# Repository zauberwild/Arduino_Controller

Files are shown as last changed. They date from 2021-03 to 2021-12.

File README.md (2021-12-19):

# Arduino_Controller

## Intro

This is a little project i did with a joystick breakout board, that usually would be used with the Micro:Bit platform. I got this breakout board for Christmas, however I don't have any Micro:Bit controllers (and didn't want to get into these ones), so I tried to make it compatible with Arduinos. For that, I broke off the connector on the PCB and soldered my own wires to it to connect to an Arduino Pro Micro.

## Communication and using the controller

### The LED

Below the jumper connector is a tiny groove, behind which a led is hiding. The led indicates the working mode:

1. Blink: controller mode
2. Blinks: serial with continuous data
3. Blinks: serial with data on event

The led will blink every time on when changing the modes and once at startup.

### Settings

The controller will as default act as a real controller to the computer. However, the serial port is always open (Baud: 9600), so you can apply some settings at any time:

1. **Communication mode:** The arduino can send the 'raw' data over its serial ports instead of acting like a real controller. In that mode, the arduino sends all data both over USB and the jumper connectors next to it at the same time, as they are the same port. More on how to process the incoming data later. You can change between these modes by simply sending `com_mode=controller` or `com_mode=serial`.
2. **Sending mode:** In serial mode, you can change between a continuous data stream with all data and data on event, which means the arduino only sends somethings, when something changed. Change this with `sending_mode=continuous` and `sending_mode=onEvent`.
3. **Joystick mode:** Sometimes having a D-pad is more useful than a joystick. For this case, you can switch between analogue and digital values for the Joystick. This settings only makes a difference in controller mode. In serial, both the analogue and digital values are send, more info on that below. That setting is changed by `joystick_mode=analog` and `joystick_mode=digital`.

The arduino will always respond with the setting you just declared or with an error, when the command couldn't be understood. You don't have to worry about newline trailers and spaces though, these are automatically removed.

**However**, I also wrote a python script that makes is it easier to change the settings. (See down below)

### Using as a controller

It's _almost_ plug'n'play. You will need to configure it though, for example in Steam's controller settings, because an Arduino is not a standard and well-known gaming controller. You might want to configure both the Joystick and the D-pad, so you will need to change modes during the process.

### Using the serial port

As previously said, you can both use the USB-port and the jumper connectors. The pinout of the latter is seen in this picture:

The arduino has a 5V operating voltage, so be warned when combining it with a 3.3V micro-controller.

*I also might write a library for arduino that would take care of all the communicating below*.

#### continuous

The data is presented as one long string, each character representing one button. The string looks something like this: `00010010x25y-103z11000`. The order of buttons in front of the letters is as follows:
`up - down - left - right - mode - l1 - r1`
Between the letters are the analogue values, reaching from -127 to 127 (left - right and up - down, meaning a movement up returns a negative number). Because the length of these numbers can change, they are bordered by letters. `'x' - potiX - 'y' - potiY - 'z'`.
After the letters are the button inside the joystick, or "z-axis", and the digital (`0/1`)values of the joystick for each direction:
`potiZ - potiUp - potiDown - potiLeft - potiRight`

#### onEvent

In that mode, the data is only send when something changes. In that case, the arduino will send the name of the button (you can see the names in the picture below), followed by a number with the new value. For example: 
- `up1` (the UP-button is pressed)
- `left0` (the LEFT-button is released)
- `potiX68` (the joystick is moved about half ways to the right)

## Materials

| Item | Price | Link (on where I found it) |
| --- | --- | --- |
| Arduino Pro Micro | 6.90€ | https://www.berrybase.de/raspberry-pi-co/arduino/boards/kompatibler-arduino-pro-micro-mit-atmel-mega-32u4-prozessor |
| Keyestudio Joystick Breakout Board for Micro:Bit | 6.41€ 9.00$ | https://www.keyestudio.com/products/keyestudio-joystick-breakout-board-for-bbc-microbit-1 |

The Arduino Pro Micro is not an official Arduino board, I think, but it uses the same processor as the Arduino Leonardo, the Atmega32u4, and appears as such. To use this board, you simply can choose the Arduino Leonardo as the board and program it rightaway.

additional material:

- 2 M3 screws, 10-15mm long
- a 3D-Printer and filament
- wires, soldering iron and tin
- two tiny breakout board push-buttons and a led

## 3D-Printing and Assembly

All the necessary .stl-files are in /cad/final. You can also find the Fusion 360 and STEP files there. For the printing I used an Anycubic I3 Mega, with silver PLA on 0.12mm layer height. All parts together took a little bit more than 24 hours, test pieces not included.

The breakout board should fit on the standoffs of the lower side part. The Led goes under the breakout board in it's hole and might needs to glued. It's then connected to GND and the Led-Pin via a resitor. The push-buttons belong in the upper part behind the shoulder buttons and are wired without any resistor, because we are using the internal INPUT_PULLUP. The micro-controller and jumper connectors belong in the upper part between the shoulder buttons. Images of the assembly and wiring diagram are in the /media/assembly folder.

## Source-Code

### Arduino-Sketch for the controller

The sketch is pretty simple and straightforward. There's one function, `blinkLed()`, everything else is done inside `void loop(){}` in that order:

1. read any incoming serial data
2. read inputs
3. sends outputs
	1. controller
	2. serial - continuous
	3. serial - on event
4. save current values as previous values

To make the arduino simulate a controller, I used the Joystick library by Matthew Heironimus (https://github.com/MHeironimus/ArduinoJoystickLibrary)

### Python-Script for easy settings

The python script is available as a pyw-file, so you can run it without a terminal.

- You can change the port in the Port-menu and Baudrate in Baudrate-Menu (although you won't have to, both this script and the arduino are set to 9600 as standard)
- You can change the modes by clicking on the buttons. The communication usually takes a moment. You can see the changed setting in the terminal. If you don't see it, try again.

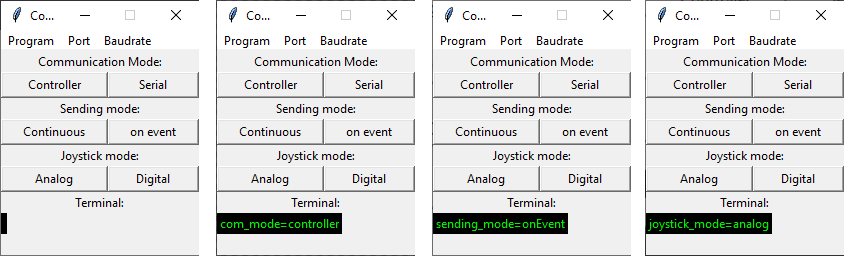
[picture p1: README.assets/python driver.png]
python driver


### Arduino library

*WIP*

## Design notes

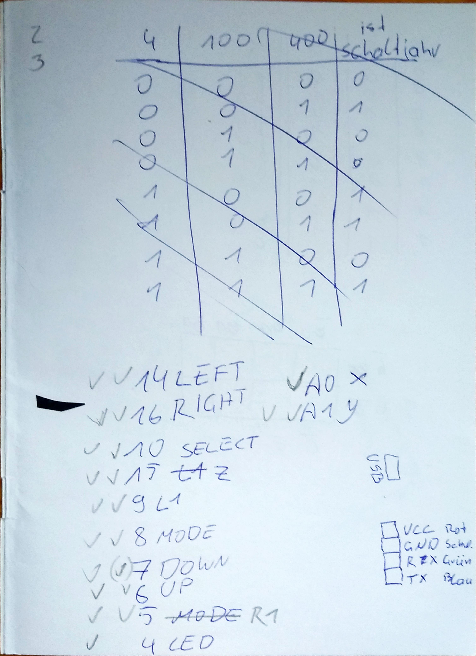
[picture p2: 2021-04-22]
media/images/notes (3).jpg

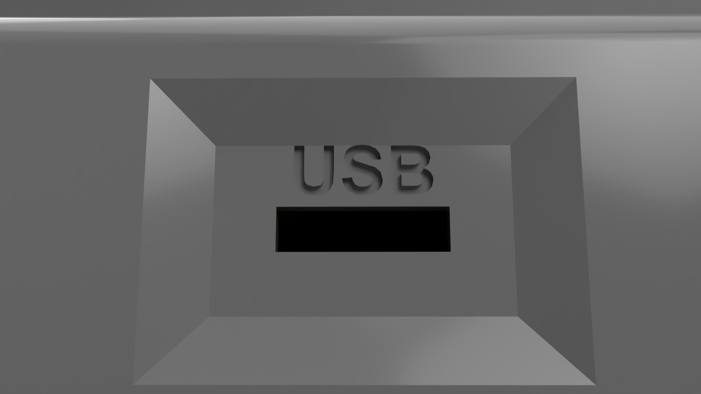
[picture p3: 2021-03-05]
cad/media/Controller_2021-Feb-25_02-03-17PM-000_CustomizedView4634732458.png

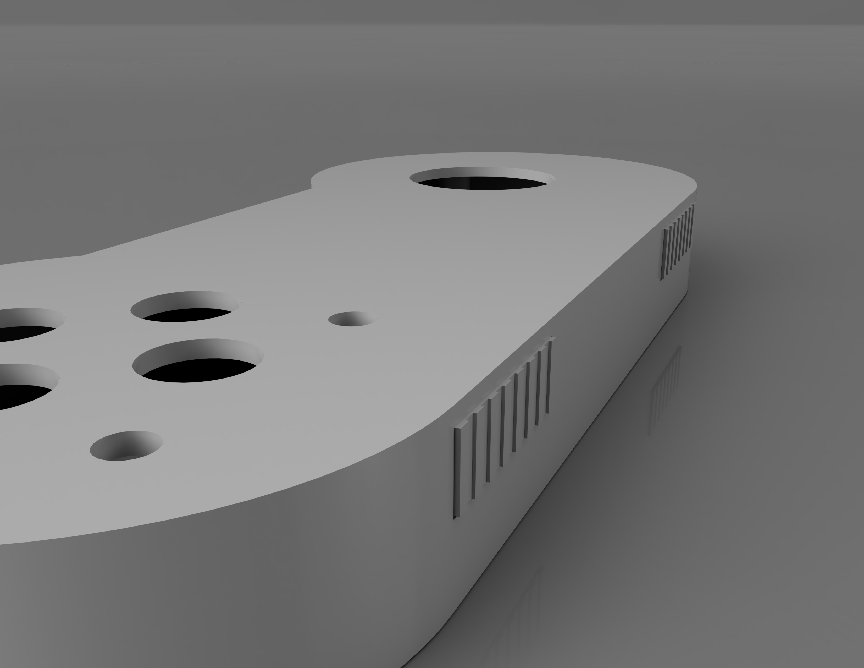
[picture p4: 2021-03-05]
cad/media/Controller v18_3.png

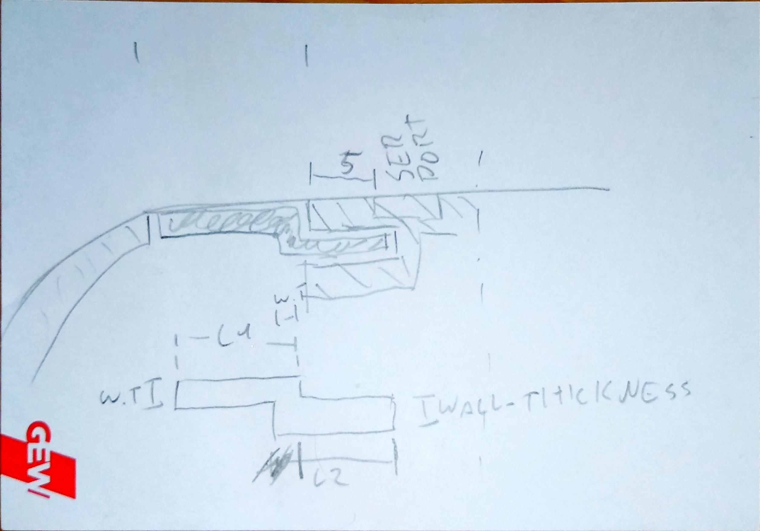
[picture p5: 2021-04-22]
media/images/notes (4).jpg

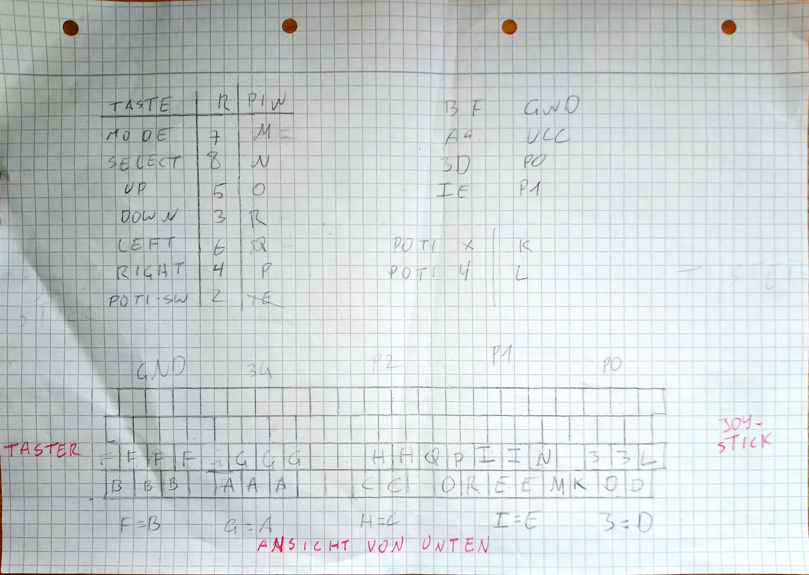
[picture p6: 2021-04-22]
media/images/notes (1).jpg

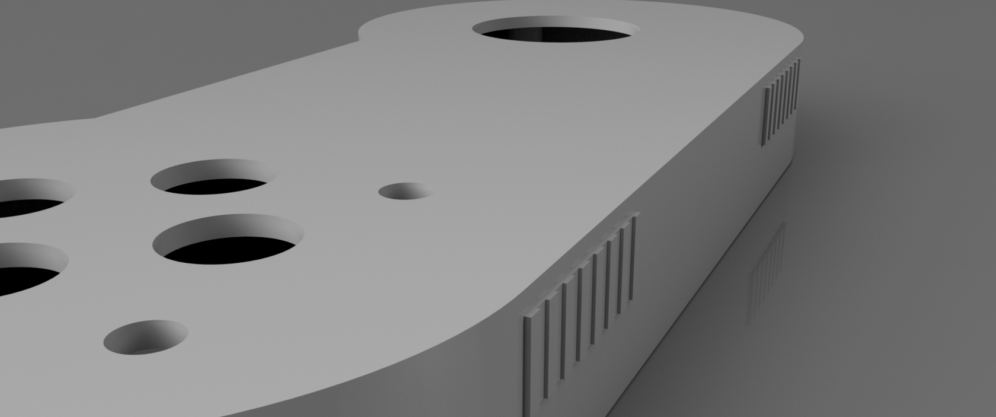
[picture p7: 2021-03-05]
cad/media/Controller v18_2.png

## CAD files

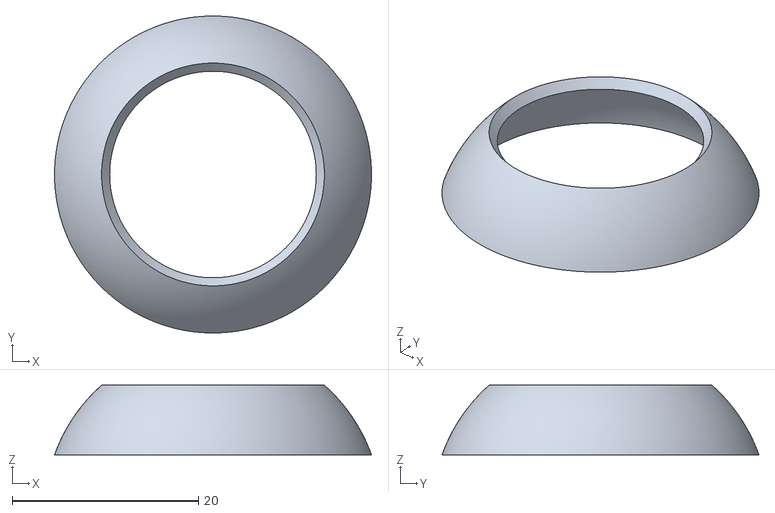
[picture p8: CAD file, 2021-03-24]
cad/final/Joystick Abdeckung.stl
34.0 x 34.0 x 7.48

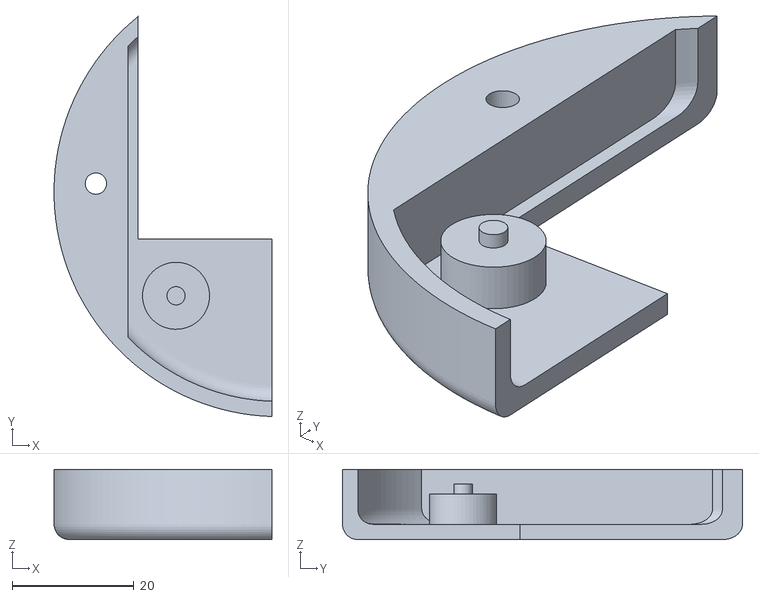
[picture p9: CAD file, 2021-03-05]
cad/test/Controller Unterseite.stl
35.8 x 65.6 x 11.5

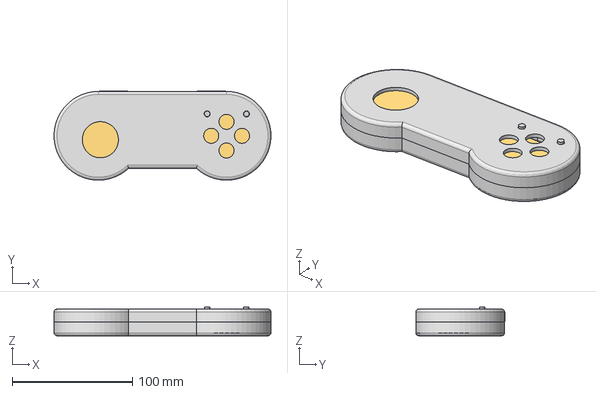
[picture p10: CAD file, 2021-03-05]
cad/final/Controller v45.step
180.2 x 74.2 x 23.7 mm

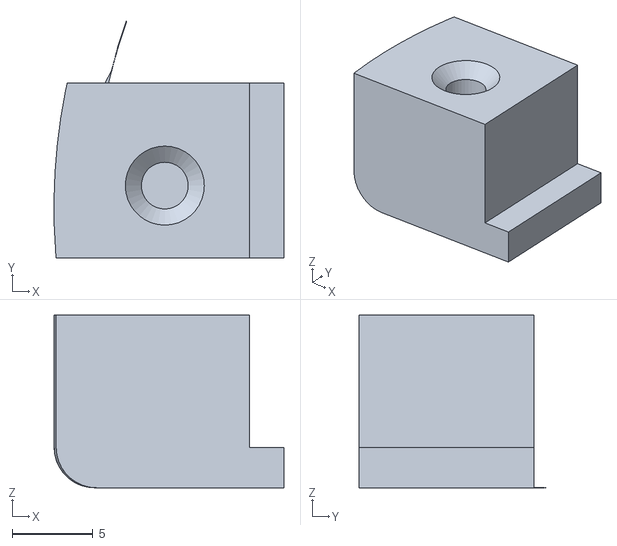
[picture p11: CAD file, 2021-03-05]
cad/test/Controller Oberseite.stl
14.3 x 14.7 x 10.7

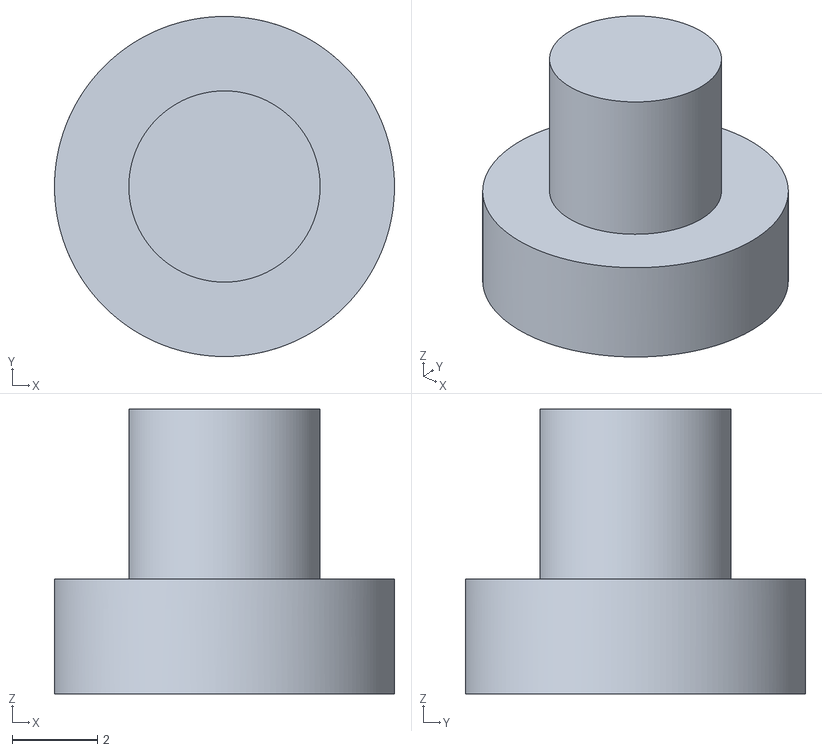
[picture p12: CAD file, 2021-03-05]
cad/final/Taster Set.stl
8.00 x 8.00 x 6.70

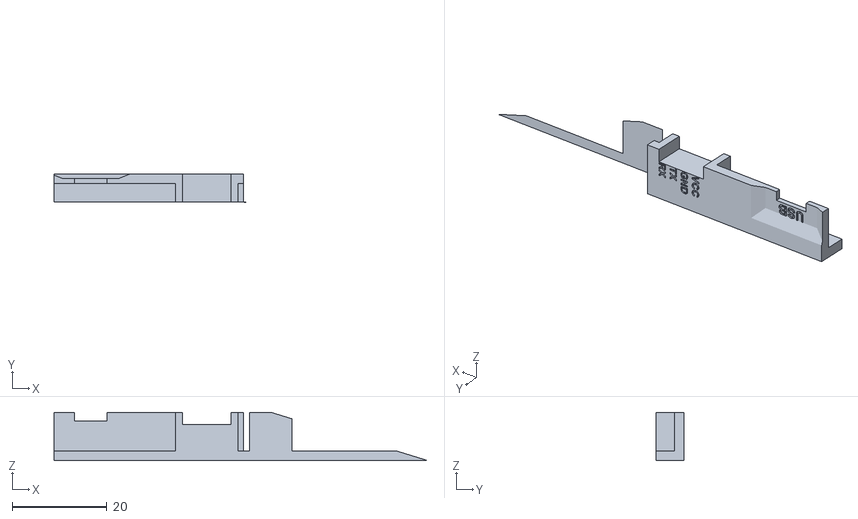
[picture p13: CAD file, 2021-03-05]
cad/test/text.stl
79.0 x 6.00 x 10.2

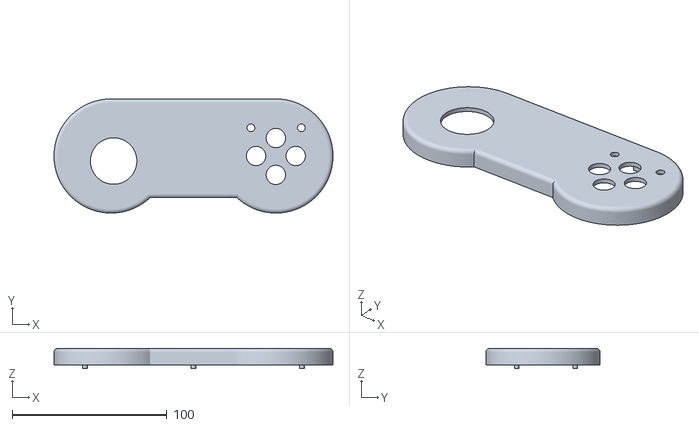
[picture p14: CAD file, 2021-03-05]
cad/final/Controller Oberseite.stl
180.2 x 73.7 x 13.1

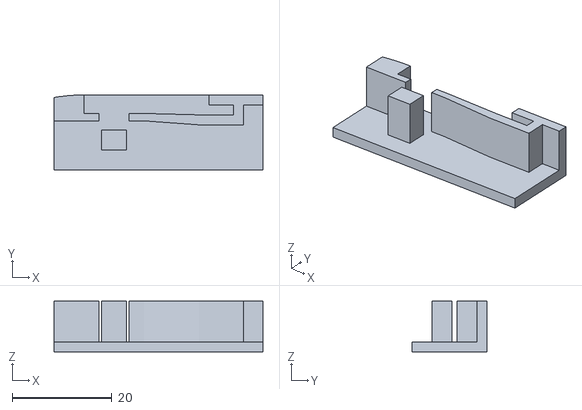
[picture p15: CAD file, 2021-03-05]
cad/test/schultertaste halterung.stl
41.9 x 15.1 x 10.2

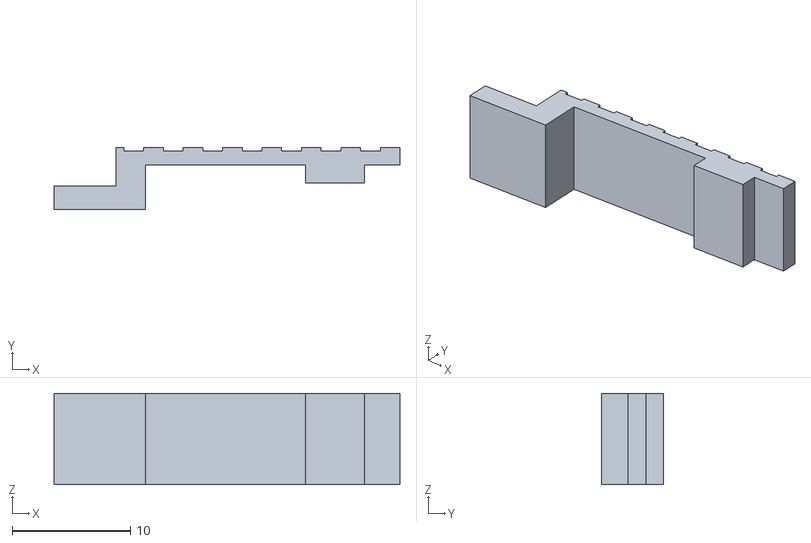
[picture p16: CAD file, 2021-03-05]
cad/final/Schultertaste R.stl
29.2 x 5.25 x 7.70

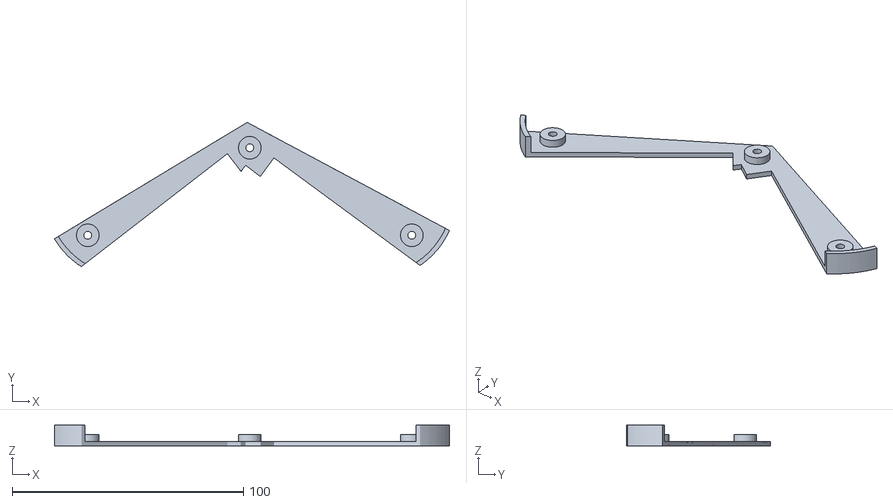
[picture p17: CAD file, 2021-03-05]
cad/test/schrauben.stl
170.9 x 62.4 x 8.99

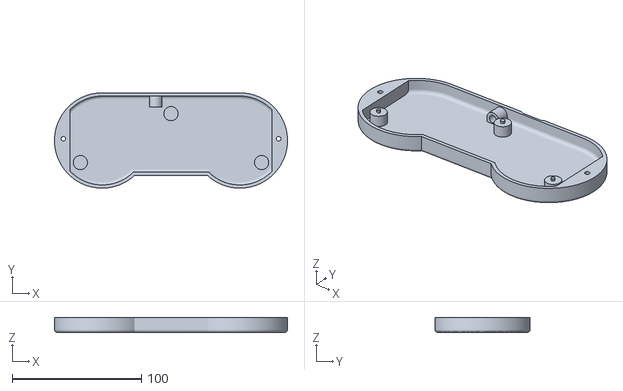
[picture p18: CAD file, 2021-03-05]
cad/final/Controller Unterseite.stl
180.2 x 73.7 x 11.6

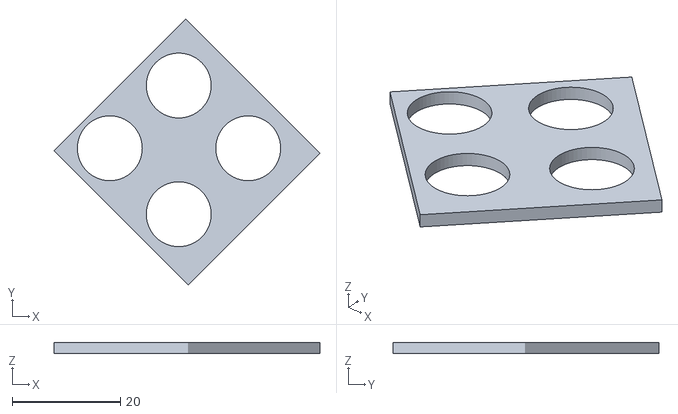
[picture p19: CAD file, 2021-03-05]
cad/test/taster.stl
49.2 x 49.2 x 2.00

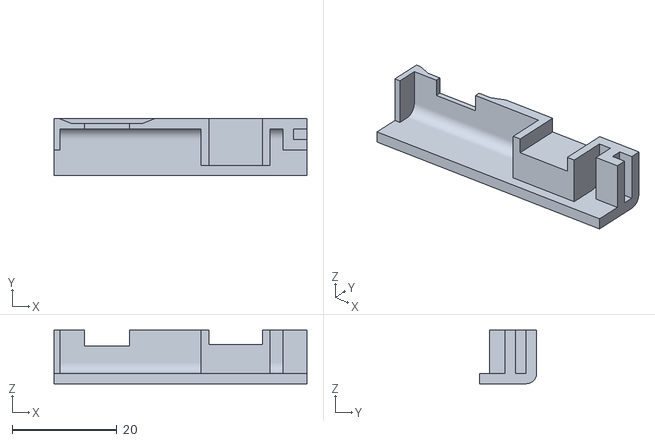
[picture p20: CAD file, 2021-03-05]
cad/test/stecker.stl
48.2 x 10.9 x 10.2

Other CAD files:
cad/final/Schultertaste L.stl
cad/final/Taster Mode.stl
cad/final/Controller v45.f3d

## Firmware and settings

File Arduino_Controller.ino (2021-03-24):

#include <Joystick.h>

// PINS
const int pinUp = 6;
const int pinDown = 7;
const int pinLeft = 14;
const int pinRight = 16;

const int pinL1 = 9;
const int pinR1 = 5;

const int pinSel = 10;
const int pinMod = 8;

const int pinPotiX = A0;
const int pinPotiY = A1;
const int pinPotiZ = 15;

const int pinLed = 4;


// OUTPUT STATES
int up = 0;				// values for buttons on the right side
int down = 0;
int left = 0;
int right = 0;

int l1 = 0;				// shoulder buttons
int r1 = 0;

int sel = 0;			// select and mode
int mod = 0;

float potiX = 0;		// analog values for joystick
float potiY = 0;
int potiZ = 0;

int potiUp = 0;			// digital values for joystick
int potiDown = 0;
int potiLeft = 0;
int potiRight = 0;


// PREVIOUS OUTPUT STATES
int prevUp = 0;
int prevDown = 0;
int prevLeft = 0;
int prevRight = 0;

int prevL1 = 0;
int prevR1 = 0;

int prevSel = 0;
int prevMod = 0;

float prevPotiX = 0;
float prevPotiY = 0;
int prevPotiZ = 0;

int prevPotiDigUp = 0;
int prevPotiDigDown = 0;
int prevPotiDigLeft = 0;
int prevPotiDigRight = 0;

float potiThreshold = 127/6;    // threshold for change on potis
float dpadThreshold = 127/2;	// threshold for dpad mode on joystick


// OPERATING MODES
enum {controller, serial};
int com_mode = controller;
/* sets the sending mode. in controller mode, the arduino will act as an actual controller,
   in serial mode the arduino will send the values over the serial port.
   change with sending on serial port: "com_mode=controller" or "com_mode=serial"
*/
enum {analog, digital};
int joystick_mode = analog;
/* this sets how the joystick will be treated. analog means the values will be sent as actual analog values,
   digital means, that the joystick will be used as a dpad / hat.
   NOTE: this only applies to controller mode. in serial mode, both is being send (analog between the letters, digital at the end of line)
   change with sending on serial port: "joystick_mode=analog" or "joystick_mode=digital"
*/
enum {continuous, onEvent};
int sending_mode = continuous;
/* this set on how the data should be send. continouos results in a continuous stream of data, onEvent only sends when something has changed.
   NOTE: this only applies to the serial port. In controller mode, the data will be send continuously in either case.
   change with sending on serial port "sending_mode=continuous" or "sending_mode=onEvent"
*/
bool autoSendState = true;

// Functions
void blinkLed(int n){
	/* lets the led blinks the desired amount of time (yes, with the all-forbidden delay())
		1x: controller mode, 2x: serial + continuous; 3x: serial + on event
	*/
	byte d = 200;
	for(int i = 0; i < n; i++){
		digitalWrite(pinLed, HIGH);
		delay(d);
		digitalWrite(pinLed, LOW);
		delay(d);
	}
}

void setup() {
  //communication
  Serial.begin(9600);
  Joystick.begin(autoSendState);
  // pinmodes
  pinMode(pinLed, OUTPUT);
  pinMode(pinL1, INPUT_PULLUP);
  pinMode(pinR1, INPUT_PULLUP);

  blinkLed(2);
  delay(350);
  blinkLed(1);
}

void loop() {
	// watch the serial port
  	if(Serial.available() > 0){
		String in = Serial.readString();
		in.trim();
		in.replace(" ", "");

		//com_mode
		if(in == "com_mode=controller"){
			com_mode = controller;
			Serial.println("com_mode=controller");
			Serial.println("Communication mode is set to controller");
			blinkLed(1);
		}
		else if(in == "com_mode=serial"){
			com_mode = serial;
			Serial.println("com_mode=serial");
			Serial.print("Communication mode is set to serial ");
			if(sending_mode==continuous) 	{blinkLed(2); Serial.println("with continuous data stream");}
			if(sending_mode==onEvent) 		{blinkLed(3); Serial.println("with data on event");}
		}

		// joystick mode
		else if (in == "joystick_mode=analog"){
			joystick_mode = analog;
			Serial.println("joystick_mode=analog");
			Serial.println("sending analog values");
		}
		else if(in == "joystick_mode=digital"){
			joystick_mode = digital;
			Serial.println("joystick_mode=digital");
			Serial.println("sending digital values");
		}

		// sending_mode
		else if(in == "sending_mode=continuous") {
			sending_mode = continuous;
			Serial.println("sending_mode=continuous");
			Serial.println("sending continuous data stream");
			blinkLed(2);
		}
		else if (in == "sending_mode=onEvent"){
			sending_mode = onEvent;
			Serial.println("sending_mode=onEvent");
			Serial.println("sending only on event");
			blinkLed(3);
		}

		// error message
		else{
			Serial.println("ERROR: '" + in + "' doesn't match with any commands");
		}
		  
  	}

	// read in data
	// buttons on the right
	up = !digitalRead(pinUp);
	down = !digitalRead(pinDown);
	left = !digitalRead(pinLeft);
	right = !digitalRead(pinRight);
	
	mod = !digitalRead(pinMod);
	sel = !digitalRead(pinSel);

	// shoulder buttons
	l1 = !digitalRead(pinL1);
	r1 = !digitalRead(pinR1);

	// joystick
	potiX = analogRead(pinPotiX);
	potiY = analogRead(pinPotiY);
	potiX = map(potiX, 0, 1023, -127, 127);
	potiY = map(potiY, 0, 1023, 127, -127);
	potiZ = !digitalRead(pinPotiZ);

	potiUp 	= potiY < -dpadThreshold;
	potiLeft = potiX < -dpadThreshold;
	potiRight = potiX > dpadThreshold;
	potiDown = potiY > dpadThreshold;

	// controller mode
	if(com_mode == controller){
		Joystick.setButton(0, down);
		Joystick.setButton(1, right);
		Joystick.setButton(2, left);
		Joystick.setButton(3, up);

		Joystick.setButton(4, l1);
		Joystick.setButton(5, r1);

		Joystick.setButton(8, sel);
		Joystick.setButton(9, mod);

		if(joystick_mode == analog){
			Joystick.setXAxis(potiX);
			Joystick.setYAxis(potiY);
			Joystick.setButton(10, potiZ);
		}else{
			Joystick.setButton(11, potiDown);
			Joystick.setButton(12, potiRight);
			Joystick.setButton(13, potiLeft);
			Joystick.setButton(14, potiUp);		
		}
	}
	// serial mode
	else if (com_mode == serial){
		// continouos stream
		if(sending_mode == continuous){
			Serial.print(up);
			Serial.print(down);
			Serial.print(left);
			Serial.print(right);
			Serial.print(mod);
			Serial.print(sel);
			Serial.print(l1);
			Serial.print(r1);
			Serial.print('x');
			Serial.print(potiX);
			Serial.print('y');
			Serial.print(potiY);
			Serial.print('z');
			Serial.print(potiZ);
			Serial.print(potiUp);
			Serial.print(potiDown);
			Serial.print(potiLeft);
			Serial.print(potiRight);
			Serial.print('\n');
		}
		else if (sending_mode == onEvent){			// TODO: change on event algorithm from for-loop to a lot of ifs
			int curState[] = {up, down, left, right, sel, mod, l1, r1, potiX, potiY, potiZ, potiUp, potiDown, potiLeft, potiRight};
			int prevState[] = {prevUp, prevDown, prevLeft, prevRight, prevSel, prevMod, prevL1, prevR1, prevPotiX, prevPotiY, prevPotiZ, prevPotiDigUp, prevPotiDigDown, prevPotiDigLeft, prevPotiDigRight};

			for(int i = 0; i < 11; i++){
				if(curState[i] != prevState[i]){			// compare states with previous states

					if (i == 8 || i == 9){		// if comparing the analog poti results
						
						if(!(curState[i] + potiThreshold > prevState[i]			// if poti value is NOT bigger or smaller than previous value by a certain amount
							|| curState[i] - potiThreshold < prevState[i])){
							continue;												// than break and don't send changes
							}
					}

					switch (i){
					case 0:
						Serial.print("up");
						break;
					case 1:
						Serial.print("down");
						break;
					case 2:
						Serial.print("left");
						break;
					case 3:
						Serial.print("right");
						break;
					case 4:
						Serial.print("sel");
						break;
					case 5:
						Serial.print("mod");
						break;
					case 6:
						Serial.print("l1");
						break;
					case 7:
						Serial.print("r1");
						break;
					case 8:
						Serial.print("potiX");
						break;
					case 9:
						Serial.print("potiY");
						break;
					case 10:
						Serial.print("potiZ");
						break;
					case 11:
						Serial.print("potiUp");
						break;
					case 12:
						Serial.print("potiDown");
						break;
					case 13:
						Serial.print("potiLeft");
						break;
					case 14:
						Serial.print("potiRight");
						break;
					default:
						Serial.print("ERR overflow");
						break;
					}

					Serial.println(curState[i]);
				}
			}
		}
		
	}
	
	// save previous states
	prevUp = up;
	prevDown = down;
	prevLeft = left;
	prevRight = right;

	prevL1 = l1;
	prevR1 = r1;

	prevSel = sel;
	prevMod = mod;

	prevPotiX = potiX;
	prevPotiY = potiY;
	prevPotiZ = potiZ;

	prevPotiDigUp = potiUp;
	prevPotiDigLeft = potiLeft;
	prevPotiDigRight = potiRight;
	prevPotiDigDown = potiDown;

  	delay(5);
}

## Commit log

2021-03-05 removed uneccessary files
    [Controller v45.obj, Controller v45.stl]
2021-03-24 Update Arduino_Controller.ino
    renamed some variables; set correct pin numbers
    [Arduino_Controller.ino]
2021-03-24 Create Joystick Abdeckung.stl
    [Joystick Abdeckung.stl]
2021-03-24 removed unnecessary cad-files
    [Schultertaste L.stl, Schultertaste R.stl, Taster Set.stl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]
2021-03-24 Create python driver.png
